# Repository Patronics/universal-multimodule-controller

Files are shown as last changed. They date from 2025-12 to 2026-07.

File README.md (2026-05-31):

# Universal Multi-Module Controller

This project aims to allow standard input devices (such as game controllers and keyboards) to control output to 4-in-one multi-module transmitters.

Created by Patrick Leiser and Josh Adriano.

## Installation
Use the [Arduino-Pico board core](https://arduino-pico.readthedocs.io/en/latest/) by Earle Philhower
Dependencies:
U8g2 by oliver
ArduinoJson by Benoit Blanchon
Bounce2 by Thomas O Fredericks
Pico PIO USB by Sekigon-gonnoc

You can program it with the Arduino IDE directly, adjust the menu options as described at the top of `GamesteerRC.ino`.

Alternatively, for advanced usage and debugging, you can install the [Arduino-CLI](https://docs.arduino.cc/arduino-cli/) and use the scripts as described below: 

## Build & Debug Scripts

---

### build.sh  
Builds a **release version** of the firmware using Arduino CLI.

- Optimized for performance (`-O2` / `-Os`)
- Produces `.elf` and `.uf2` in `build/`
- Use when you want final or production-like firmware

---

### debug-build.sh  
Builds a **debug version** of the firmware.

- Uses `-Og` optimization for good debugging behavior
- Includes full debug symbols (`-g`)
- Outputs to `build-debug/`
- Use when stepping through code or inspecting variables with GDB

---

### flash.sh  
Flashes firmware using the **Raspberry Pi Debug Probe (OpenOCD + SWD)**.

- Programs the `.elf` directly to flash
- Verifies and resets the device
- Use for fast iteration during debugging

---

### openocd.sh  
Starts the **OpenOCD GDB server**.

- Provides a debugging connection on port 3333
- Required before connecting GDB
- Use when preparing a debug session

---

### gdb.sh  
Launches **GDB for source-level debugging**.

- Connects to OpenOCD (`localhost:3333`)
- Uses the project `.elf`
- Use for breakpoints, stepping, and inspecting state
- See debugging section below for additional details
---

### upload.sh  
Flashes firmware using the **UF2 bootloader (USB mode)**.
- uses `arduino-cli upload`
- Before use, edit upload.sh with the port of your target device, such as `/dev/cu.usbmodem101` or `COM7`
  - Alternatively, you can manually boot the device into BOOTSEL mode, and copy `build/GamesteerRC.ino.uf2` onto the device.
- No debugger needed
- Use for simple deployment or recovery
---

### Typical usage
Call the scripts from the top level of the directory, such as `./scripts/build.sh`
- **Development (debugging):** `debug-build.sh` → `flash.sh` → `openocd.sh` → *(in a second terminal session)* `gdb.sh`
- **Quick standalone flash:** `build.sh → upload.sh`

## Debugging
For debugging, once OpenOCD and GDB are active, within GDB run 
```gdb
target extended-remote :3333
monitor reset halt
break panic
continue

```

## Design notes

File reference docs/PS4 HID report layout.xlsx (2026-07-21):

PS4 HID report layout
Byte index | Sample Report Value | Input Name | Bit mask | notes
0 | 01
1 | 76 | LX | FF | fully supported analog input
2 | 80 | LY | FF | fully supported analog input
3 | 7E | RX | FF | fully supported analog input
4 | 80 | RY | FF | fully supported analog input
5 | 08 |  | 10 | Square button
 |  |  | 20 | X button
 |  |  | 40 | Circle button
 |  |  | 80 | Triangle Button
 |  |  | 0F | D-pad: 08=unpressed, 00 through 07= Directions and diagonals clockwise from up
6 | 00 |  | 01 | L1 Pressed
 |  |  | 02 | R1 Pressed
 |  |  | 10 | Share button pressed
 |  |  | 20 | Options button pressed
 |  |  | 40 | Left Joystick (L3) pressed
 |  |  | 80 | Right Joystick (R3) pressed
7 | 60 |  | FC | Report counter, increments with each incoming report
8 | 00 | LT | FF | fully supported analog input (L2)
9 | 00 | RT | FF | fully supported analog input (R2)
10 | 7F |  |  | Start of Gyro/Accel data?
11 | B4 |  |  | Continued gyro/accel data?
12 | 0C |  |  | Continued gyro/accel data?
13 | 19 |  |  | Continued gyro/accel data?
14 | 00 |  |  | Continued gyro/accel data?
15 | 0D |  |  | Continued gyro/accel data?
16 | 00 |  |  | Continued gyro/accel data?
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

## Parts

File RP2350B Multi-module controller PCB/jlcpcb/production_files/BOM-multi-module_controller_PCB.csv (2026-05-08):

Comment | Designator | Footprint | LCSC | Quantity
0 | R10 | R_0402_1005Metric | C17168 | 1
0.1u | C25 | C_0402_1005Metric | C1525 | 1
100n | C11,C12,C13,C14,C15,C16,C17,C18,C2,C20,C21,C23,C26,C8 | C_0402_1005Metric | C1525 | 14
10k | R15,R16 | R_0402_1005Metric | C25744 | 2
10u | C1,C19,C5 | C_0805_2012Metric | C15850 | 3
15p | C3,C4 | C_0402_1005Metric | C7467172 | 2
1k | R2,R4,R6 | R_0402_1005Metric | C11702 | 3
22 | R20,R21,R22,R26 | R_0402_1005Metric | C25092 | 4
27 | R7,R8 | R_0402_1005Metric | C25100 | 2
3.3u | L1 | L_pol_2016 | C42411119 | 1
33 | R3 | R_0402_1005Metric | C25105 | 1
33k | R14,R18 | R_0402_1005Metric | C25779 | 2
4.7u | C10,C6,C7,C9 | C_0402_1005Metric | C23733 | 4
470 | R25 | R_0603_1608Metric | C23179 | 1
47k | R17,R19 | R_0402_1005Metric | C25792 | 2
47u | C24,C27 | C_1206_3216Metric | C96123 | 2
56k | R23,R24 | R_0402_1005Metric | C2906875 | 2
5k1 | R12,R5 | R_0402_1005Metric | C25905 | 2
ABM8-272-T3 | Y1 | Crystal_SMD_3225-4Pin_3.2x2.5mm | C20625731 | 1
BTN_BACK | SW8 | SW_Push_1P1T_NO_E-Switch_TL3301NxxxxxG | C2837532 | 1
BTN_DOWN | SW6 | SW_Push_1P1T_NO_E-Switch_TL3301NxxxxxG | C2837532 | 1
BTN_LEFT | SW3 | SW_Push_1P1T_NO_E-Switch_TL3301NxxxxxG | C2837532 | 1
BTN_MDL | SW10 | SW_Push_1P1T_NO_E-Switch_TL3301NxxxxxG | C2837532 | 1
BTN_OK | SW5 | SW_Push_1P1T_NO_E-Switch_TL3301NxxxxxG | C2837532 | 1
BTN_RIGHT | SW7 | SW_Push_1P1T_NO_E-Switch_TL3301NxxxxxG | C2837532 | 1
BTN_SYS | SW9 | SW_Push_1P1T_NO_E-Switch_TL3301NxxxxxG | C2837532 | 1
BTN_UP | SW4 | SW_Push_1P1T_NO_E-Switch_TL3301NxxxxxG | C2837532 | 1
FSUSB42MUX | U5 | MSOP-10_3x3mm_P0.5mm | C11355 | 1
LED | D1 | LED_0603_1608Metric | C7496818 | 1
MIC2026-1xM | U6 | SOIC-8_3.9x4.9mm_P1.27mm | C144190 | 1
Module_Bay | J7 | PinHeader_1x08_P2.54mm_Vertical | C19184340 | 1
NCP1117-3.3_SOT223 | U2 | SOT-223-3_TabPin2 | C88234 | 1
RP2350_80QFN | U1 | RP2350-QFN-80-1EP_10x10_P0.4mm_EP3.4x3.4mm_ThermalVias | C42415655 | 1
SW_Push | SW1,SW2 | SW_Push_1P1T_NO_Vertical_Wuerth_434133025816 | C2910644 | 2
USB_A | J8 | USB_A_Connfly_DS1095 | C456018 | 1
USB_C_Receptacle_USB2.0_14P | J5,J6 | USB_C_Receptacle_G-Switch_GT-USB-7010ASV | C2988369 | 2
W25Q128JVS | U3 | SOIC-8_5.23x5.23mm_P1.27mm | C97521 | 1
~ | DS1 | Waveshare 1.54in OLED |  | 1
SM03B-SRSS-TB | J4 | PinHeader_1x03_P2.54mm_Vertical |  | 1
DNF | R1 | R_0402_1005Metric |  | 1
MountingHole | H2 | MountingHole_2.7mm_M2.5 |  | 1
MountingHole | H3 | MountingHole_2.7mm_M2.5 |  | 1
MountingHole | H1 | MountingHole_2.7mm_M2.5 |  | 1
MountingHole | H4 | MountingHole_2.7mm_M2.5 |  | 1
DNF | R9 | R_0402_1005Metric |  | 1
DNF | U4 | SOIC-8_5.23x5.23mm_P1.27mm |  | 1
DNF | R11 | R_0402_1005Metric |  | 1
DNF | R13 | R_0402_1005Metric |  | 1
DNF | C22 | C_0402_1005Metric |  | 1
ADC_Breakout | J9 | PinHeader_2x09_P2.54mm_Vertical |  | 1
Conn_02x06_Odd_Even | J1 | PinSocket_2x06_P2.54mm_Vertical |  | 1
Internal unused GPIO Breakout | J10 | PinHeader_2x03_P1.27mm_Vertical |  | 1

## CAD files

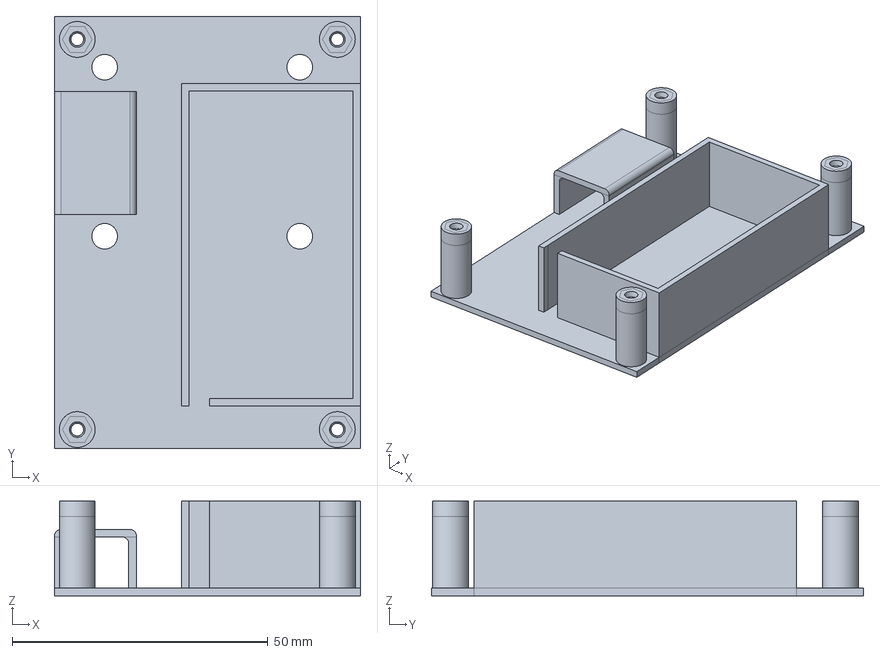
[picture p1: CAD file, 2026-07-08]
3D models/Case.FCStd
59.8 x 84.4 x 18.5 mm

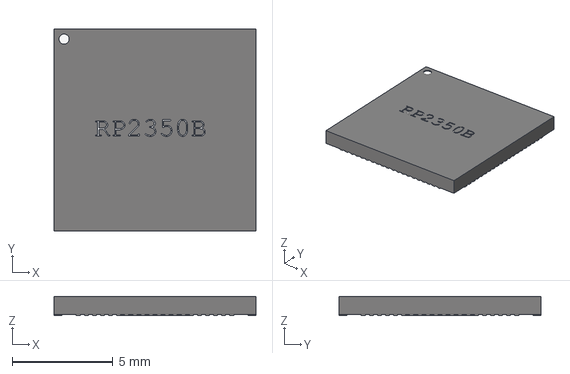
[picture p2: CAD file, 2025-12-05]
RP2350B Multi-module controller PCB/RP2350_QFN80.step
10.0 x 10.0 x 0.95 mm

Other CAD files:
3D models/PCBv1-1.step

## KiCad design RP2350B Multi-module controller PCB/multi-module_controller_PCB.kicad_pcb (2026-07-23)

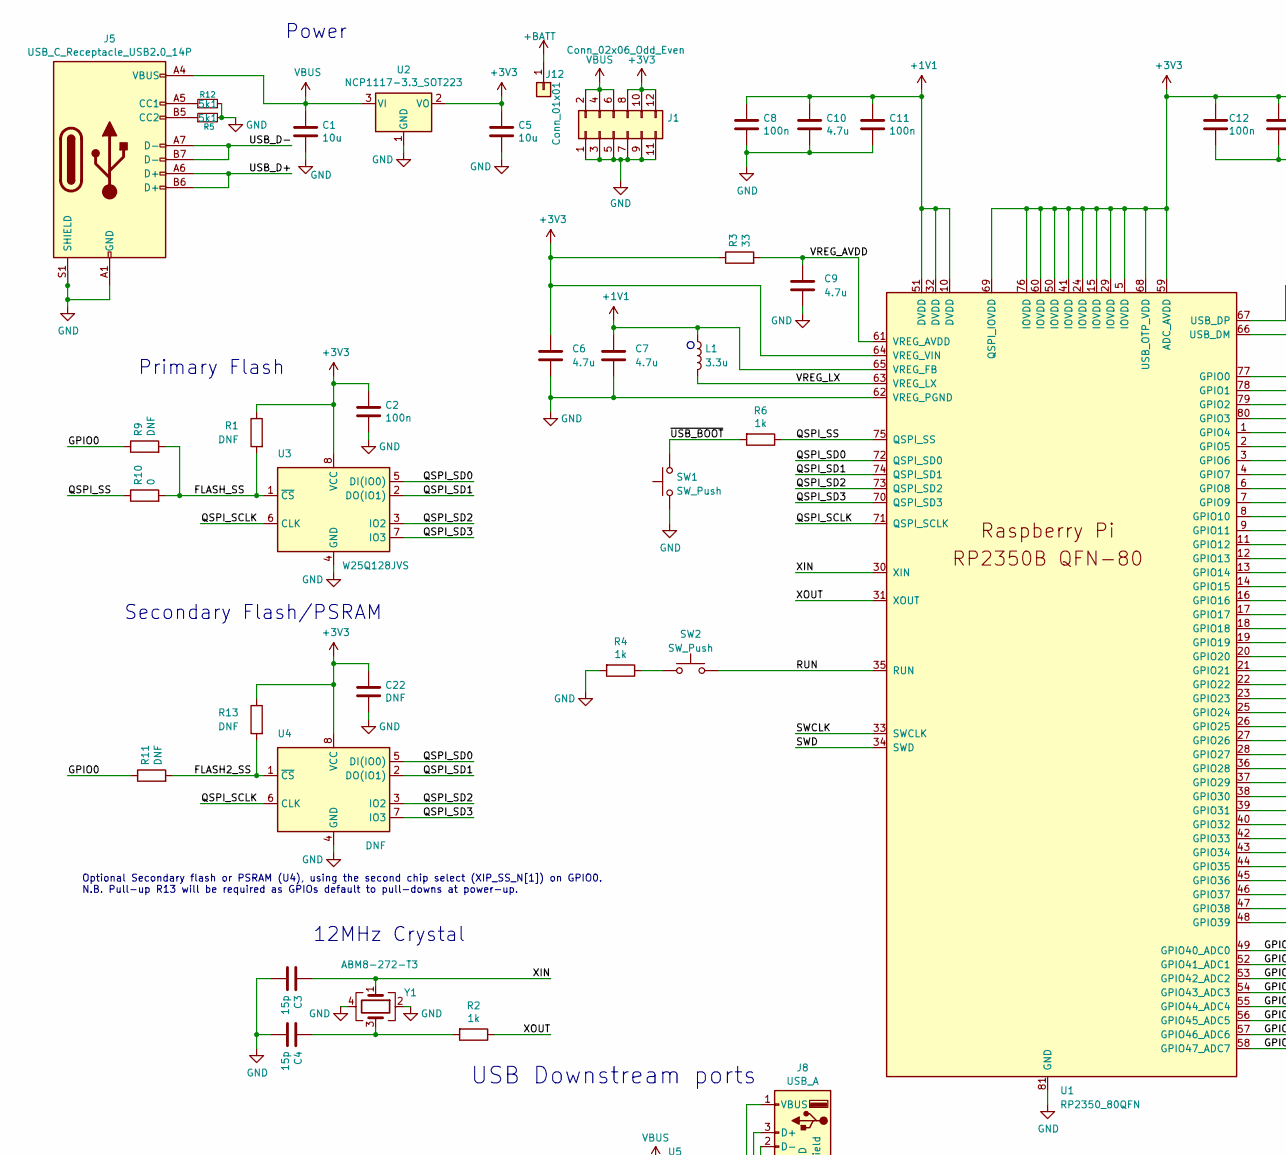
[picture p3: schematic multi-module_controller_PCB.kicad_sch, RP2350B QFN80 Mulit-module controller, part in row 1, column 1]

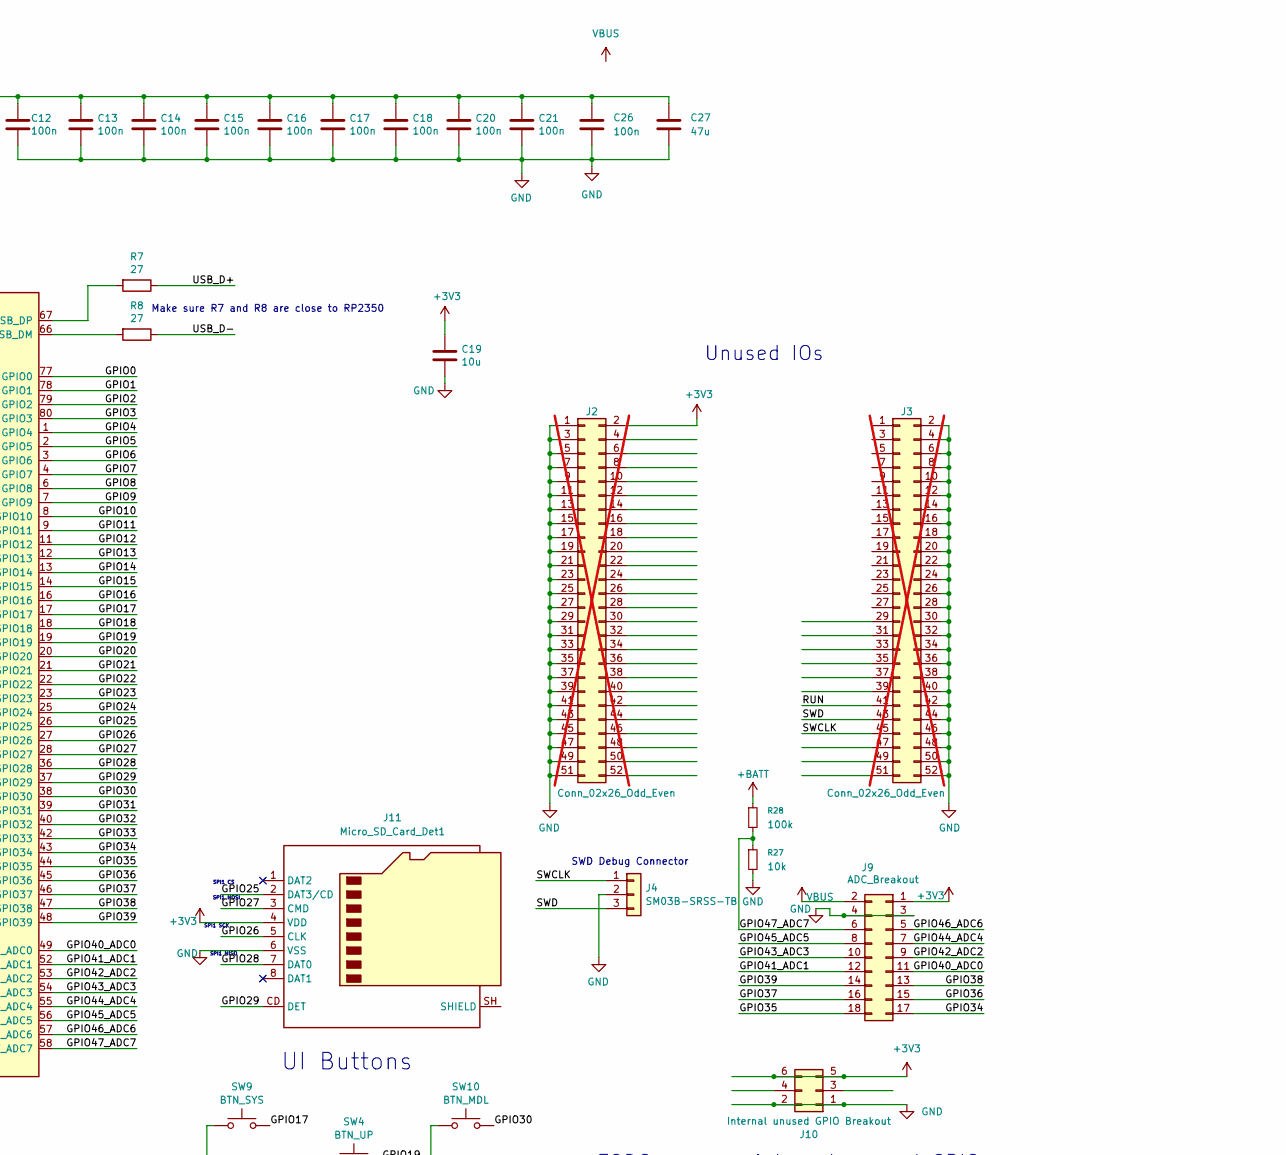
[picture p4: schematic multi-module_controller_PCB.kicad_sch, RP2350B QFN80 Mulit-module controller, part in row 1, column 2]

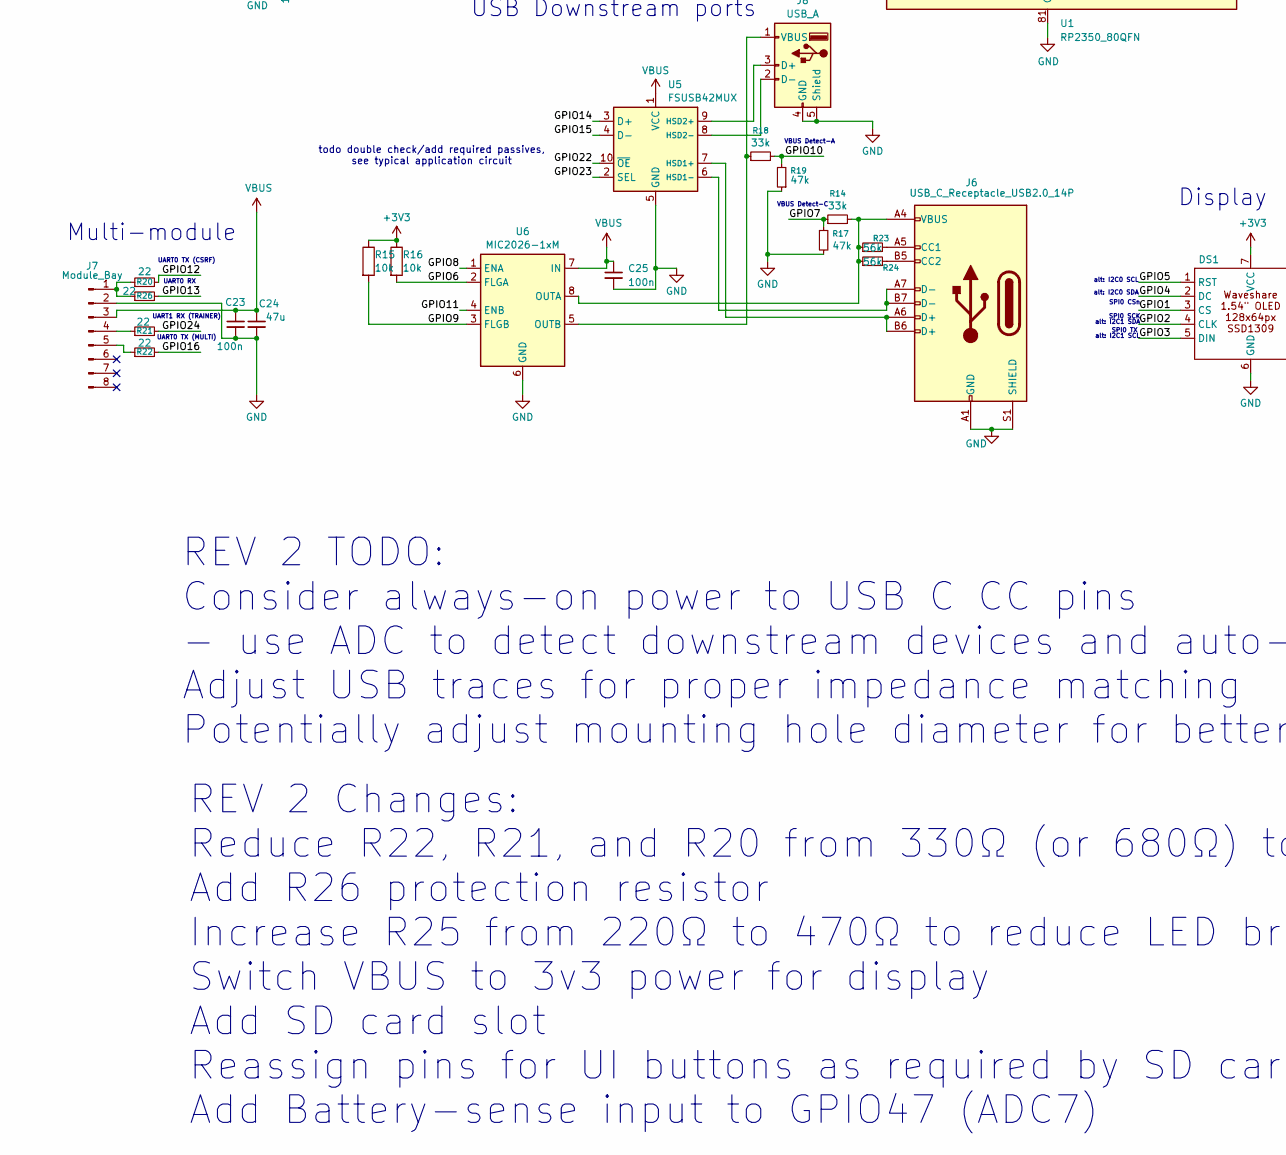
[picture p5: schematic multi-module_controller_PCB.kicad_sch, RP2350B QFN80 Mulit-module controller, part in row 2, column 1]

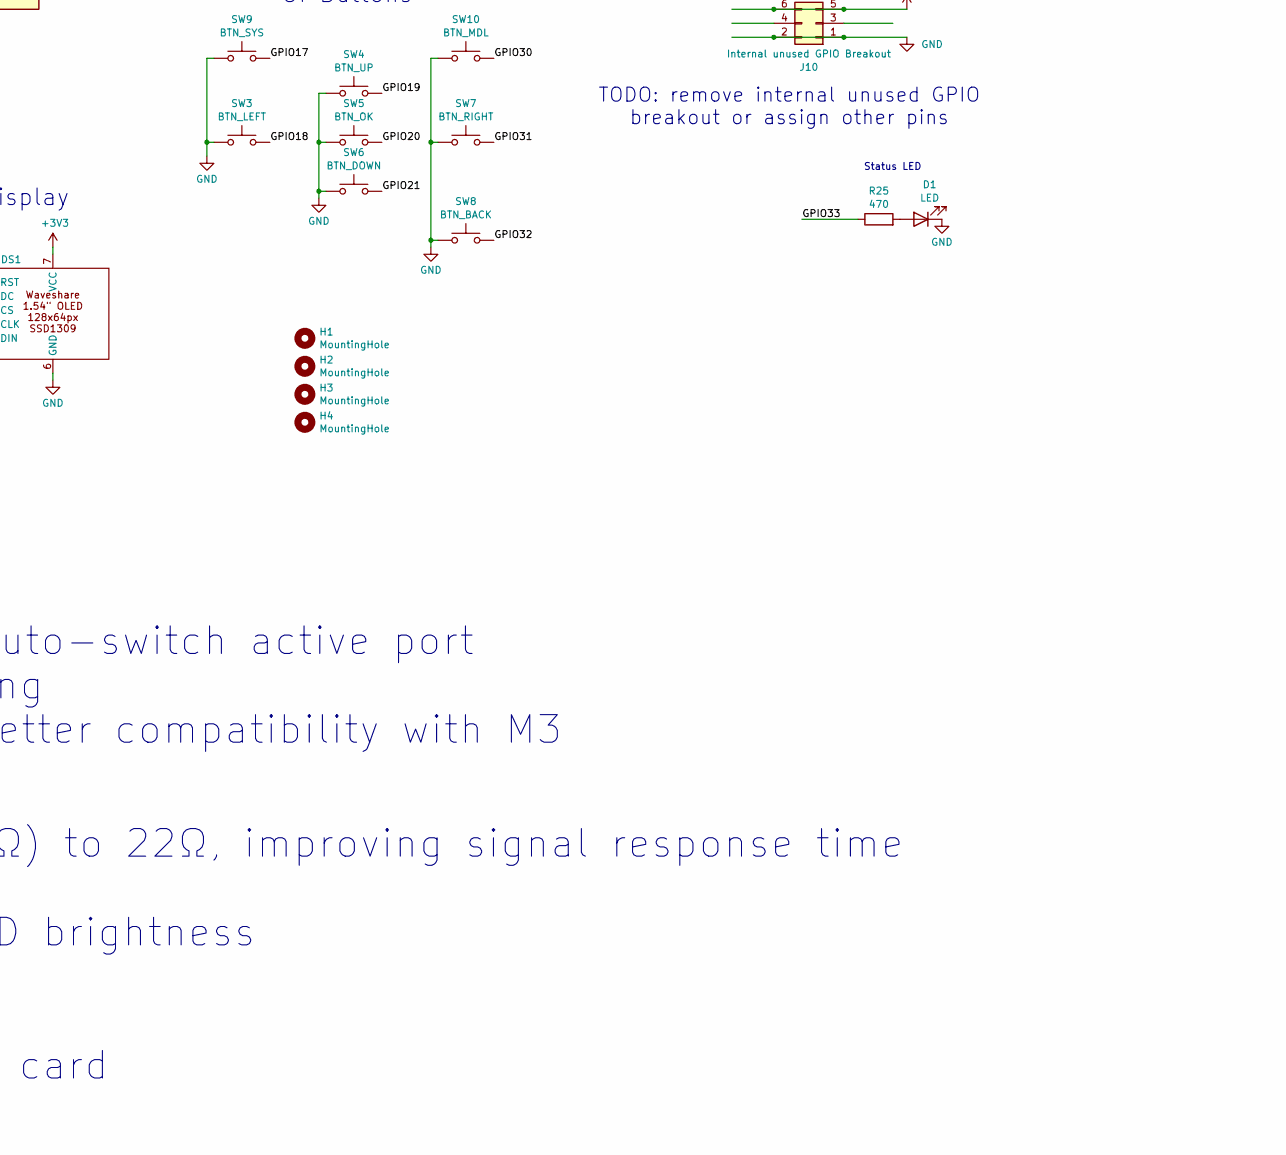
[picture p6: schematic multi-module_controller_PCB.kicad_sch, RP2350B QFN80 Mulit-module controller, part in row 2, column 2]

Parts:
C1, C5, C19: 10u; C_0805_2012Metric; LCSC C15850
C2, C8, C11, C12, C13, C14, C15, C16, C17, C18, C20, C21, C23, C25: 100n; C_0402_1005Metric; LCSC C1525
C3, C4: 15p; C_0402_1005Metric; LCSC C7467172
C6, C7: 4.7u; C_0402_1005Metric_small_pads; LCSC C23733
C9, C10: 4.7u; C_0402_1005Metric; LCSC C23733
C22: DNF; C_0402_1005Metric
C24: 47u; C_1206_3216Metric; LCSC C16780
C26: 100n; C_0402_1005Metric
C27: 47u; C_1206_3216Metric
D1: LED; LED_0603_1608Metric; LCSC C7496818
DS1: Waveshare 1.54in OLED
H1, H2, H3, H4: MountingHole; MountingHole_3.2mm_M3
J1: Conn_02x06_Odd_Even; PinSocket_2x06_P2.54mm_Vertical
J2, J3: Conn_02x26_Odd_Even; PinHeader_2x26_P2.54mm_Vertical; not fitted
J4: SM03B-SRSS-TB; PinHeader_1x03_P2.54mm_Vertical
J5, J6: USB_C_Receptacle_USB2.0_14P; USB_C_Receptacle_G-Switch_GT-USB-7010ASV; LCSC C2988369
J7: Module_Bay; PinHeader_1x08_P2.54mm_Vertical; LCSC C19184340
J8: USB_A; USB_A_Connfly_DS1095; LCSC C456018
J9: ADC_Breakout; PinHeader_2x09_P2.54mm_Vertical
J10: Internal unused GPIO Breakout; PinHeader_2x03_P1.27mm_Vertical
J11: Micro_SD_Card_Det1; SD-SMD_MLD-TF-PUSH-H18
J12: Conn_01x01; PinHeader_1x01_P2.54mm_Vertical
L1: 3.3u; L_pol_2016; LCSC C42411119
R1, R9, R11, R13: DNF; R_0402_1005Metric
R2, R4, R6: 1k; R_0402_1005Metric; LCSC C11702
R3: 33; R_0402_1005Metric; LCSC C25105
R5, R12: 5k1; R_0402_1005Metric; LCSC C25905
R7, R8: 27; R_0402_1005Metric; LCSC C25100
R10: 0; R_0402_1005Metric; LCSC C17168
R14, R18: 33k; R_0402_1005Metric; LCSC C25744
R15, R16: 10k; R_0402_1005Metric; LCSC C25744
R17, R19: 47k; R_0402_1005Metric; LCSC C25792
R20, R26: 22; R_0402_1005Metric; LCSC C25130
R21, R22: 22; R_0402_1005Metric; LCSC C25104
R23, R24: 56k; R_0402_1005Metric; LCSC C2906875
R25: 470; R_0603_1608Metric; LCSC C22962
R27: 10k; R_0402_1005Metric
R28: 100k; R_0402_1005Metric
SW1, SW2: SW_Push; SW_Push_1P1T_NO_Vertical_Wuerth_434133025816; LCSC C2910644
SW3: BTN_LEFT; SW_Push_1P1T_NO_E-Switch_TL3301NxxxxxG; LCSC C2837532
SW4: BTN_UP; SW_Push_1P1T_NO_E-Switch_TL3301NxxxxxG; LCSC C2837532
SW5: BTN_OK; SW_Push_1P1T_NO_E-Switch_TL3301NxxxxxG; LCSC C2837532
SW6: BTN_DOWN; SW_Push_1P1T_NO_E-Switch_TL3301NxxxxxG; LCSC C2837532
SW7: BTN_RIGHT; SW_Push_1P1T_NO_E-Switch_TL3301NxxxxxG; LCSC C2837532
SW8: BTN_BACK; SW_Push_1P1T_NO_E-Switch_TL3301NxxxxxG; LCSC C2837532
SW9: BTN_SYS; SW_Push_1P1T_NO_E-Switch_TL3301NxxxxxG; LCSC C2837532
SW10: BTN_MDL; SW_Push_1P1T_NO_E-Switch_TL3301NxxxxxG; LCSC C2837532
U1: RP2350_80QFN; RP2350-QFN-80-1EP_10x10_P0.4mm_EP3.4x3.4mm_ThermalVias; LCSC C42415655
U2: NCP1117-3.3_SOT223; SOT-223-3_TabPin2; LCSC C88234
U3: W25Q128JVS; SOIC-8_5.23x5.23mm_P1.27mm; LCSC C97521
U4: DNF; SOIC-8_5.23x5.23mm_P1.27mm
U5: FSUSB42MUX; MSOP-10_3x3mm_P0.5mm; LCSC C11355
U6: MIC2026-1xM; SOIC-8_3.9x4.9mm_P1.27mm; LCSC C144190
Y1: ABM8-272-T3; Crystal_SMD_3225-4Pin_3.2x2.5mm; LCSC C20625731

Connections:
+1V1: C7.1, C8.1, C10.1, C11.1, L1.1, U1.10 (DVDD), U1.32 (DVDD), U1.51 (DVDD), U1.65 (VREG_FB)
+3V3: C2.1, C5.1, C6.1, C12.1, C13.1, C14.1, C15.1, C16.1, C17.1, C18.1, C19.1, C20.1, C21.1, C22.1, C26.1, C27.1, DS1.7 (VCC), J1.8, J1.10, J1.12, J2.2, J9.1, J10.5, J10.6, J11.4 (VDD), R1.1, R3.1, R13.1, R15.1, R16.1, U1.5 (IOVDD), U1.15 (IOVDD), U1.24 (IOVDD), U1.29 (IOVDD), U1.41 (IOVDD), U1.50 (IOVDD), U1.59 (ADC_AVDD), U1.60 (IOVDD), U1.64 (VREG_VIN), U1.68 (USB_OTP_VDD), U1.69 (QSPI_IOVDD), U1.76 (IOVDD), U2.2 (VO), U3.8 (VCC), U4.8 (VCC)
+BATT: J12.1 (Pin_1_1), R28.1
/FLASH2_SS: R11.2, R13.2, U4.1 (~CS)
/FLASH_SS: R1.2, R9.2, R10.2, U3.1 (~CS)
/GPIO0: R9.1, R11.1, U1.77 (GPIO0)
/GPIO1: DS1.3 (CS), U1.78 (GPIO1)
/GPIO2: DS1.4 (CLK), U1.79 (GPIO2)
/GPIO3: DS1.5 (DIN), U1.80 (GPIO3)
/GPIO4: DS1.2 (DC), U1.1 (GPIO4)
/GPIO5: DS1.1 (RST), U1.2 (GPIO5)
/GPIO6: R16.2, U1.3 (GPIO6), U6.2 (FLGA)
/GPIO7: R14.1, R17.1, U1.4 (GPIO7)
/GPIO8: U1.6 (GPIO8), U6.1 (ENA)
/GPIO9: R15.2, U1.7 (GPIO9), U6.3 (FLGB)
/GPIO10: R18.2, R19.2, U1.8 (GPIO10)
/GPIO11: U1.9 (GPIO11), U6.4 (ENB)
/GPIO12: R20.2, U1.11 (GPIO12)
/GPIO13: R26.2, U1.12 (GPIO13)
/GPIO14: U1.13 (GPIO14), U5.3 (D+)
/GPIO15: U1.14 (GPIO15), U5.4 (D-)
/GPIO16: R22.2, U1.16 (GPIO16)
/GPIO17: SW9.2, U1.17 (GPIO17)
/GPIO18: SW3.2, U1.18 (GPIO18)
/GPIO19: SW4.2, U1.19 (GPIO19)
/GPIO20: SW5.2, U1.20 (GPIO20)
/GPIO21: SW6.2, U1.21 (GPIO21)
/GPIO22: U1.22 (GPIO22), U5.10 (~OE)
/GPIO23: U1.23 (GPIO23), U5.2 (SEL)
/GPIO24: R21.2, U1.25 (GPIO24)
/GPIO25: J11.2 (DAT3/CD), U1.26 (GPIO25)
/GPIO26: J11.5 (CLK), U1.27 (GPIO26)
/GPIO27: J11.3 (CMD), U1.28 (GPIO27)
/GPIO28: J11.7 (DAT0), U1.36 (GPIO28)
/GPIO29: J11.CD (DET), U1.37 (GPIO29)
/GPIO30: SW10.2, U1.38 (GPIO30)
/GPIO31: SW7.2, U1.39 (GPIO31)
/GPIO32: SW8.2, U1.40 (GPIO32)
/GPIO33: R25.1, U1.42 (GPIO33)
/GPIO34: J9.17, U1.43 (GPIO34)
/GPIO35: J9.18, U1.44 (GPIO35)
/GPIO36: J9.15, U1.45 (GPIO36)
/GPIO37: J9.16, U1.46 (GPIO37)
/GPIO38: J9.13, U1.47 (GPIO38)
/GPIO39: J9.14, U1.48 (GPIO39)
/GPIO40_ADC0: J9.11, U1.49 (GPIO40_ADC0)
/GPIO41_ADC1: J9.12, U1.52 (GPIO41_ADC1)
/GPIO42_ADC2: J9.9, U1.53 (GPIO42_ADC2)
/GPIO43_ADC3: J9.10, U1.54 (GPIO43_ADC3)
/GPIO44_ADC4: J9.7, U1.55 (GPIO44_ADC4)
/GPIO45_ADC5: J9.8, U1.56 (GPIO45_ADC5)
/GPIO46_ADC6: J9.5, U1.57 (GPIO46_ADC6)
/GPIO47_ADC7: J9.6, R27.1, R28.2, U1.58 (GPIO47_ADC7)
/QSPI_SCLK: U1.71 (QSPI_SCLK), U3.6 (CLK), U4.6 (CLK)
/QSPI_SD0: U1.72 (QSPI_SD0), U3.5 (DI(IO0)), U4.5 (DI(IO0))
/QSPI_SD1: U1.74 (QSPI_SD1), U3.2 (DO(IO1)), U4.2 (DO(IO1))
/QSPI_SD2: U1.73 (QSPI_SD2), U3.3 (IO2), U4.3 (IO2)
/QSPI_SD3: U1.70 (QSPI_SD3), U3.7 (IO3), U4.7 (IO3)
/QSPI_SS: R6.1, R10.1, U1.75 (QSPI_SS)
/RUN: J3.41, SW2.2, U1.35 (RUN)
/SWCLK: J3.45, J4.1, U1.33 (SWCLK)
/SWD: J3.43, J4.3, U1.34 (SWD)
/USB_D+: J5.A6 (D+), J5.B6 (D+), R7.1
/USB_D-: J5.A7 (D-), J5.B7 (D-), R8.1
/VREG_AVDD: C9.1, R3.2, U1.61 (VREG_AVDD)
/VREG_LX: L1.2, U1.63 (VREG_LX)
/XIN: C3.1, U1.30 (XIN), Y1.1
/XOUT: R2.1, U1.31 (XOUT)
/~USB_BOOT: R6.2, SW1.2
GND: C1.2, C2.2, C3.2, C4.2, C5.2, C6.2, C7.2, C8.2, C9.2, C10.2, C11.2, C12.2, C13.2, C14.2, C15.2, C16.2, C17.2, C18.2, C19.2, C20.2, C21.2, C22.2, C23.2, C24.2, C25.2, C26.2, C27.2, D1.1 (K), DS1.6 (GND), J1.1, J1.3, J1.5, J1.7, J1.9, J1.11, J2.1, J2.3, J2.5, J2.7, J2.9, J2.11, J2.13, J2.15, J2.17, J2.19, J2.21, J2.23, J2.25, J2.27, J2.29, J2.31, J2.33, J2.35, J2.37, J2.39, J2.41, J2.43, J2.45, J2.47, J2.49, J2.51, J3.2, J3.4, J3.6, J3.8, J3.10, J3.12, J3.14, J3.16, J3.18, J3.20, J3.22, J3.24, J3.26, J3.28, J3.30, J3.32, J3.34, J3.36, J3.38, J3.40, J3.42, J3.44, J3.46, J3.48, J3.50, J3.52, J4.2, J5.A1 (GND), J5.A12 (GND), J5.B1 (GND), J5.B12 (GND), J5.S1 (SHIELD), J6.A1 (GND), J6.A12 (GND), J6.B1 (GND), J6.B12 (GND), J6.S1 (SHIELD), J7.2, J8.4 (GND), J8.5 (Shield), J9.3, J9.4, J10.1, J10.2, J11.6 (VSS), R4.2, R5.2, R12.2, R17.2, R19.1, R27.2, SW1.1, SW3.1, SW4.1, SW5.1, SW6.1, SW7.1, SW8.1, SW9.1, SW10.1, U1.62 (VREG_PGND), U1.81 (GND), U2.1 (GND), U3.4 (GND), U4.4 (GND), U5.5 (GND), U6.6 (GND), Y1.2, Y1.4
unnamed: C4.1, R2.2, Y1.3
unnamed: D1.2 (A), R25.2
unnamed: J5.A5 (CC1), R12.1
unnamed: J5.B5 (CC2), R5.1
unnamed: J6.A5 (CC1), R23.2
unnamed: J6.B5 (CC2), R24.2
unnamed: J7.1, R20.1, R26.1
unnamed: J7.4, R21.1
unnamed: J7.5, R22.1
unnamed: J8.3 (D+), U5.9 (HSD2+)
unnamed: J8.2 (D-), U5.8 (HSD2-)
unnamed: J8.1 (VBUS), R18.1, U6.5 (OUTB)
unnamed: R4.1, SW2.1
unnamed: R8.2, U1.66 (USB_DM)
unnamed: R7.2, U1.67 (USB_DP)
unnamed: J6.A6 (D+), J6.B6 (D+), U5.7 (HSD1+)
unnamed: J6.A7 (D-), J6.B7 (D-), U5.6 (HSD1-)
unnamed: J6.A4 (VBUS), J6.A9 (VBUS), J6.B4 (VBUS), J6.B9 (VBUS), R14.2, R23.1, R24.1, U6.8 (OUTA)
VBUS: C1.1, C23.1, C24.1, C25.1, J1.2, J1.4, J1.6, J5.A4 (VBUS), J5.A9 (VBUS), J5.B4 (VBUS), J5.B9 (VBUS), J7.3, J9.2, U2.3 (VI), U5.1 (VCC), U6.7 (IN)

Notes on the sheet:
Optional Secondary flash or PSRAM (U4), using the second chip select (XIP_SS_N[1]) on GPIO0. N.B. Pull-up R13 will be required as GPIOs default to pull-downs at power-up.
REV 2 TODO: Consider always-on power to USB C CC pins - use ADC to detect downstream devices and auto-switch active port Adjust USB traces for proper impedance matching Potentially adjust mounting hole diameter for better compatibility with M3
Unused IOs
12MHz Crystal
SPI0 SCK
SPI1 SCK
alt: I2C0 SCL
UART0 TX (CSRF)
VBUS Detect-C
UART0 TX (MULTI)
SPI1 CS
Multi-module
UI Buttons
Status LED
Primary Flash
SPI1 MOSI
alt: I2C1 SCL
REV 2 Changes: Reduce R22, R21, and R20 from 330Ω (or 680Ω) to 22Ω, improving signal response time Add R26 protection resistor Increase R25 from 220Ω to 470Ω to reduce LED brightness Switch VBUS to 3v3 power for display Add SD card slot Reassign pins for UI buttons as required by SD card Add Batter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
USB Downstream ports
todo double check/add required passives, see typical application circuit
SWD Debug Connector
UART1 RX (TRAINER)
TODO: remove internal unused GPIO breakout or assign other pins
Make sure R7 and R8 are close to RP2350
VBUS Detect-A
Secondary Flash/PSRAM
Display
alt: I2C0 SDA
UART0 RX
alt: I2C1 SDA
Power
SPI0 CSn
SPI0 TX
SPI1 MISO

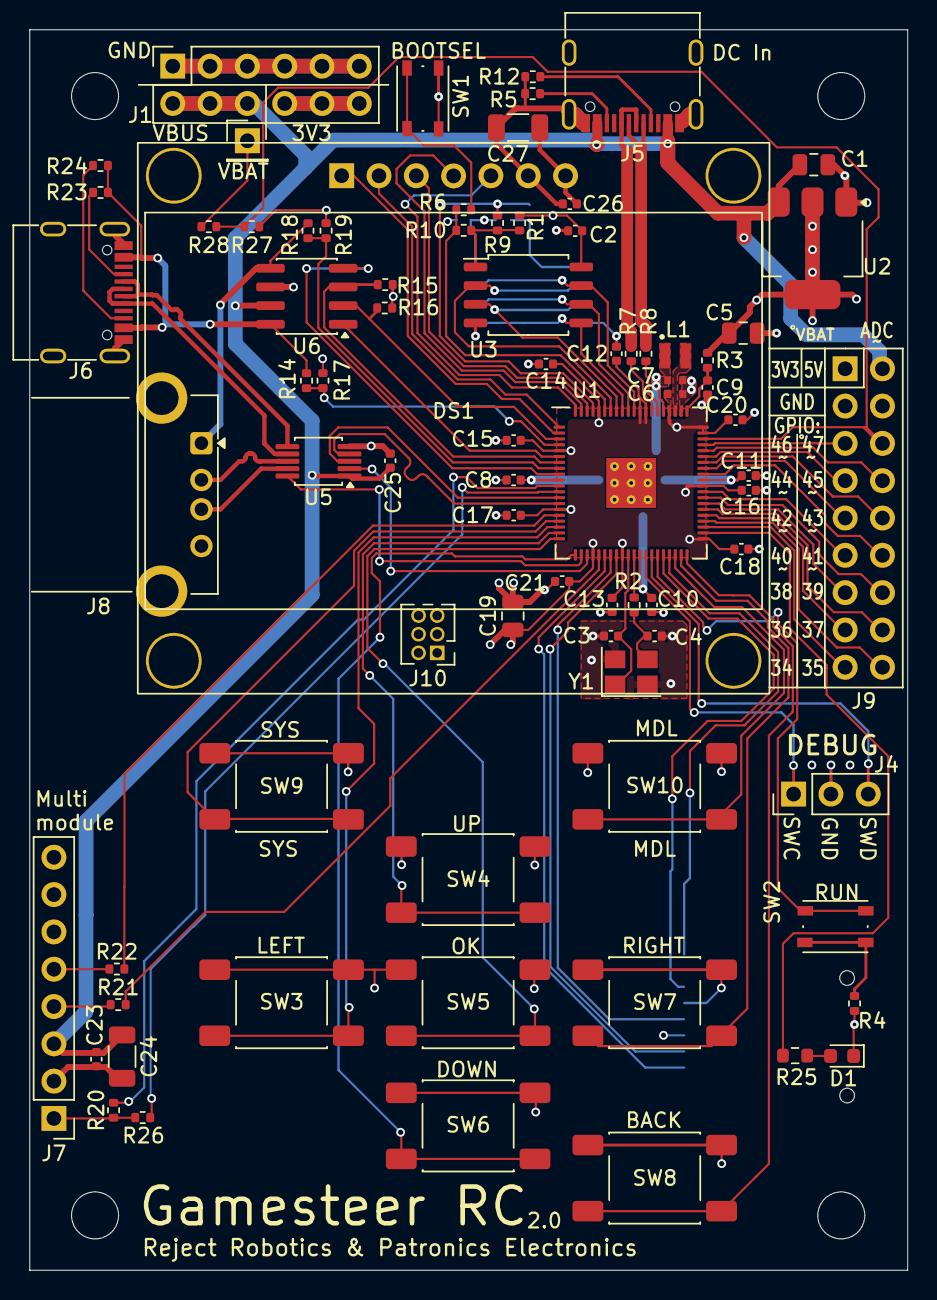
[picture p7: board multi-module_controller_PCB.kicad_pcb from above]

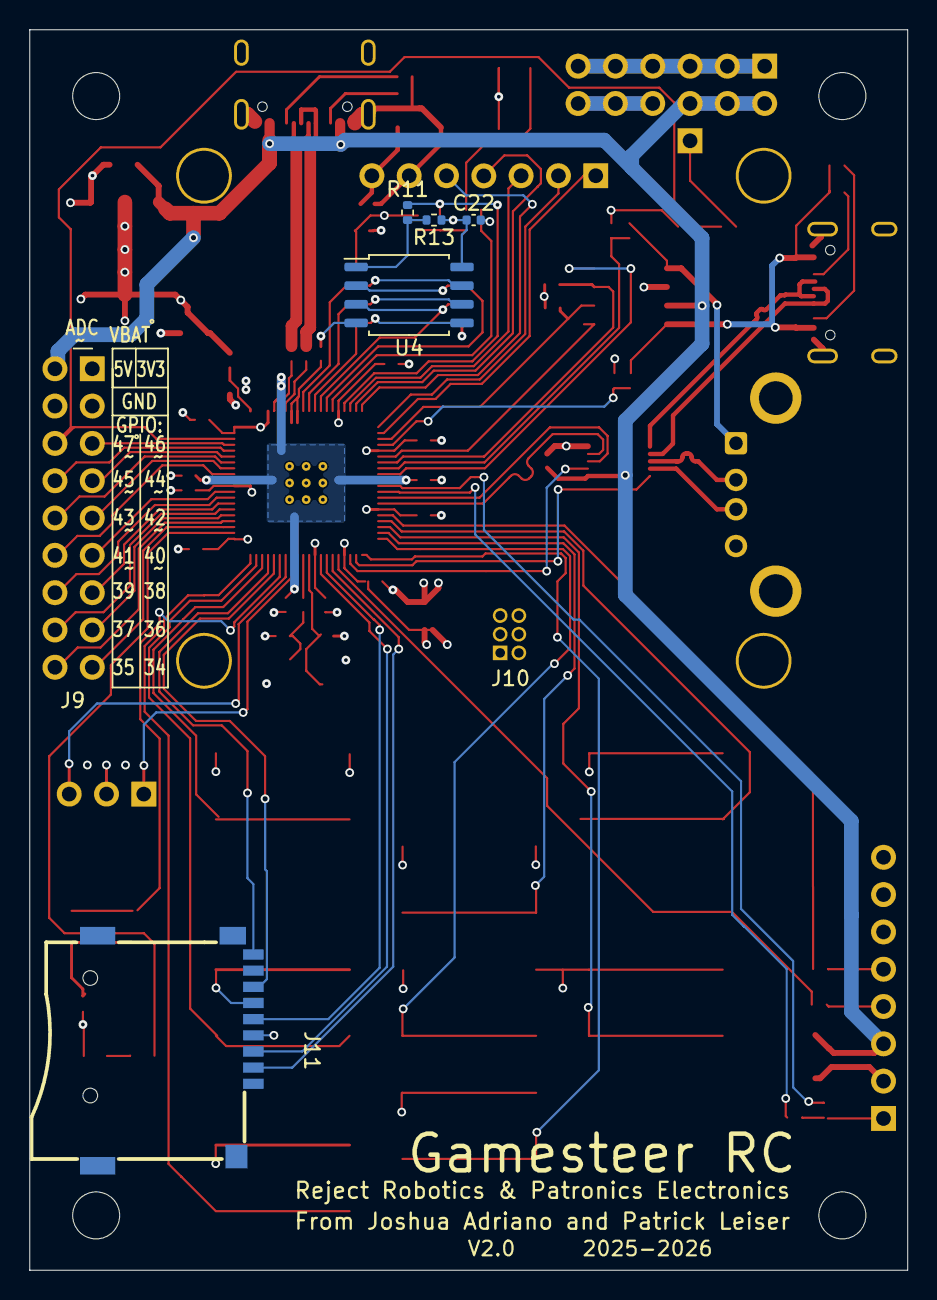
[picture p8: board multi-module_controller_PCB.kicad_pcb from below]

Board: 4 copper layers, 59.8 x 84.4 mm, 89 parts (5 on the bottom side), 89 nets.

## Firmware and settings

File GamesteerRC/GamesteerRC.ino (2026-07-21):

/*
TelemetryLogger.ino
Written By Patrick Leiser
Runs on Raspberry Pi Pico or similar RP2040 family boards
This script reads telemetry data from a 4-in-one multimodule.
*/

/*note: in arduino IDE, select:
  - Board "Raspberry Pi Pico > Generic RP2350" (from Earle Philhower)
  - Flash Size: 16MB (Sketch 8MB, FS 8MB)
  - CPU Speed: 240MHz (Overclock)
  - USB Stack: Adafruit TinyUSB
  - Chip Variant "RP2350B"
*/

//Note: DEBUG_FLAGS must be defined before including UI.h. See UI.h for list of valid flags
#define DEBUG_FLAGS (DEBUG_TRANSMIT|DEBUG_FS|DEBUG_SAVELOAD|DEBUG_LOG|DEBUG_WARN|DEBUG_ERROR|DEBUG_CORE)
//available flags: DEBUG_TIME|DEBUG_USB|DEBUG_USB_REPORT|DEBUG_TRANSMIT|DEBUG_MULTIMODULE|DEBUG_FS|DEBUG_SAVELOAD|DEBUG_LOG|DEBUG_WARN|DEBUG_ERROR|DEBUG_CORE


#include "MultiModule.h"
#include "ChannelManager.h"
#include "UI.h"
#include "controllerData.h"

// USBHost is defined in usbh_helper.h
#include "usbh_helper.h"

#include <VFS.h>
#include <LittleFS.h>
#include <ArduinoJson.h>

#include <U8g2lib.h>
#ifdef U8X8_HAVE_HW_SPI
#include <SPI.h>
#endif
#ifdef U8X8_HAVE_HW_I2C
#include <Wire.h>
#endif

#include <Bounce2.h>

//UART constants to configure:
//adjust as needed for other platforms or Serial Ports
#define SerialModule Serial1
//comment out the following defines if on a non-RP2040 platform where UART pins are fixed
#define SERIAL_MODULE_RX_PIN 13
#define SERIAL_MODULE_TX_PIN 16
#define SERIAL_MODULE_INVERT_RX


const unsigned long SERIAL_MODULE_BAUD_RATE = 100000;
const int SERIAL_MODULE_BUFFER_SIZE = 128;


unsigned long lastTelemetryMillis = 0;
unsigned long lastLoopMillis = 0;
unsigned long lastTxMillis = 0;

const unsigned long msBetweenTxUpdates = 7;

//currently unused, for saving persistient system-wide settings
struct persistent_settings {
  char enabled_port;
  uint8_t default_protocol_mode;
  uint8_t default_subprotocol_mode;
};

int current_active_model = -1;

//Select active USB port, either 'A' or 'C', or 'Z' to prompt clean-up and shutdown of the ports
volatile char requested_usb_port = 'C';
volatile char active_usb_port = requested_usb_port;
volatile bool usb_ready_flag = false; //flag set by USB core when USB device is detected and ready

OutputChannelDescriptor outChannels[MAX_CHANNELS]; //declare 16 item OutputChannelDescriptor array
MixerChannelDescriptor mixerChannels[MAX_MIXERS];
InputDescriptorPool inChannelsPool;
InputChannelDescriptor* failsafeChannels[MAX_CHANNELS];


//#define USE_I2C_DISPLAY
#define USE_PRIMARY_SPI_DISPLAY
//#define USE_SW_2ND_SPI_DISPLAY
//#define USE_HW_2ND_SPI_DISPLAY

//setup i2c display (used in pre-release hardware, slower than SPI display interfaces)
#ifdef USE_I2C_DISPLAY
  //U8G2_SSD1306_128X64_NONAME_F_HW_I2C u8g2(U8G2_R0, /* reset=*/ U8X8_PIN_NONE);
  #define I2C_DISPLAY_SDA_PIN 4
  #define I2C_DISPLAY_SCL_PIN 5
#endif

//the primary intended display interface
//for PCB 1.0, the display's VCC pin connection to VBUS MUST be bypassed, instead connect display's VCC to 3V3
#ifdef USE_PRIMARY_SPI_DISPLAY
  #define USE_HW_SPI_DISPLAY
  #define SPI_DISPLAY_RST_PIN 5
  #define SPI_DISPLAY_DC_PIN 4
  #define SPI_DISPLAY_CS_PIN 1
  #define SPI_DISPLAY_CLK_PIN 2
  #define SPI_DISPLAY_TX_PIN 3
  U8G2_SSD1309_128X64_NONAME0_F_4W_HW_SPI u8g2(U8G2_R0, SPI_DISPLAY_CS_PIN,SPI_DISPLAY_DC_PIN, SPI_DISPLAY_RST_PIN);

#endif

//convenient pinout for using display with GPIO header pins 3v3, gnd, and GPIO 46, 44, 42, 40, 38
//software-spi only so limited to 300khz clock rate
#ifdef USE_SW_2ND_SPI_DISPLAY
  #define SPI_DISPLAY_RST_PIN 38
  #define SPI_DISPLAY_DC_PIN 40
  #define SPI_DISPLAY_CS_PIN 42
  #define SPI_DISPLAY_CLK_PIN 44
  #define SPI_DISPLAY_TX_PIN 46
  U8G2_SSD1309_128X64_NONAME0_F_4W_SW_SPI u8g2(U8G2_R0, SPI_DISPLAY_CLK_PIN, SPI_DISPLAY_TX_PIN, SPI_DISPLAY_CS_PIN,SPI_DISPLAY_DC_PIN, SPI_DISPLAY_RST_PIN);
#endif

//use the gpio header pins with hardware SPI, improved performance over USE_SW_2ND_SPI_DISPLAY, but more complex pin layout
#ifdef USE_HW_2ND_SPI_DISPLAY
  #define USE_HW_SPI_DISPLAY
  #define SPI_DISPLAY_RST_PIN 46
  #define SPI_DISPLAY_DC_PIN 44
  #define SPI_DISPLAY_CS_PIN 37
  #define SPI_DISPLAY_CLK_PIN 34
  #define SPI_DISPLAY_TX_PIN 35
  U8G2_SSD1309_128X64_NONAME0_F_4W_HW_SPI u8g2(U8G2_R0, SPI_DISPLAY_CS_PIN,SPI_DISPLAY_DC_PIN, SPI_DISPLAY_RST_PIN);
#endif

#define LED_PIN 33

//UI buttons
#define OK_BUTTON_PIN 28
#define BACK_BUTTON_PIN 32
#define UP_BUTTON_PIN 27
#define DOWN_BUTTON_PIN 29
#define LEFT_BUTTON_PIN 26
#define RIGHT_BUTTON_PIN 31
#define SYS_BUTTON_PIN 25
#define MDL_BUTTON_PIN 30

const uint16_t BUTTON_DEBOUNCE_INTERVAL = 5;
#define BUTTON_INPUT_TYPE INPUT_PULLUP
#define BUTTON_PRESSED_STATE LOW

Bounce2::Button okButton;
Bounce2::Button backButton;
Bounce2::Button upButton;
Bounce2::Button downButton;
Bounce2::Button leftButton;
Bounce2::Button rightButton;
Bounce2::Button sysButton;
Bounce2::Button mdlButton;

//for picking a menu
int selectedMenu = 0;
//the currently open menu, or -1 for none
int currentMenu = -1;

const int CURRENT_MENU_NONE = -1;

int menuSubpageIndex = 0;  //for arbitrary use by sub-menu logic, should be reset to zero on exit from submenu
void *menuSubpageContext = NULL; //for arbitrary use for more advanced state in submenu logic, should be properly freed on exit of submenu
int menuUpdateCycleCount =0; //counter to update menu periodically if needed

menuItem sysMenu[MENU_ITEM_COUNT];
menuItem mdlMenu[MENU_ITEM_COUNT];

menuItem* menuItems = mdlMenu;


// USB Language ID: English
#define LANGUAGE_ID 0x0409

// CFG_TUH_DEVICE_MAX is defined by tusb_config header
usb_dev_info_t usb_raw_descriptors[CFG_TUH_DEVICE_MAX] = { 0 };

USBInputDeviceDescriptor USBDeviceDescriptors[MAX_USB_DEVICE_DESCRIPTORS];
uint8_t numberOfDeviceDescriptors = 0;

//data structures for status and output
char capturedData[MAX_TELEM_DATA_BYTES + 1]; // Pre-allocated buffer, +1 for null-terminator
MultiModuleStatus moduleStatus;

MultiProtocolStream streamOut;
uint8_t streamOutAdditionalProtocolDataLen = 0;

uint8_t currentActiveProtocol = 0;
uint8_t currentActiveSubProtocol = 0;

bool transmitActive = false;
bool failsafeActive = false;
bool haveTelemetry = false;




void setup() {

  Serial.begin(115200); //init USB serial
  pinMode(LED_PIN,OUTPUT);
  digitalWrite(LED_PIN, HIGH);

  //bounce2 setup
  okButton.attach(OK_BUTTON_PIN, BUTTON_INPUT_TYPE);
  backButton.attach(BACK_BUTTON_PIN, BUTTON_INPUT_TYPE);
  upButton.attach(UP_BUTTON_PIN, BUTTON_INPUT_TYPE);
  downButton.attach(DOWN_BUTTON_PIN, BUTTON_INPUT_TYPE);
  leftButton.attach(LEFT_BUTTON_PIN, BUTTON_INPUT_TYPE);
  rightButton.attach(RIGHT_BUTTON_PIN, BUTTON_INPUT_TYPE);
  sysButton.attach(SYS_BUTTON_PIN, BUTTON_INPUT_TYPE);
  mdlButton.attach(MDL_BUTTON_PIN, BUTTON_INPUT_TYPE);

  //debounce interval
  okButton.interval(BUTTON_DEBOUNCE_INTERVAL);
  backButton.interval(BUTTON_DEBOUNCE_INTERVAL);
  upButton.interval(BUTTON_DEBOUNCE_INTERVAL);
  downButton.interval(BUTTON_DEBOUNCE_INTERVAL);
  leftButton.interval(BUTTON_DEBOUNCE_INTERVAL);
  rightButton.interval(BUTTON_DEBOUNCE_INTERVAL);
  sysButton.interval(BUTTON_DEBOUNCE_INTERVAL);
  mdlButton.interval(BUTTON_DEBOUNCE_INTERVAL);

  okButton.setPressedState(BUTTON_PRESSED_STATE);
  backButton.setPressedState(BUTTON_PRESSED_STATE);
  upButton.setPressedState(BUTTON_PRESSED_STATE);
  downButton.setPressedState(BUTTON_PRESSED_STATE);
  leftButton.setPressedState(BUTTON_PRESSED_STATE);
  rightButton.setPressedState(BUTTON_PRESSED_STATE);
  sysButton.setPressedState(BUTTON_PRESSED_STATE);
  mdlButton.setPressedState(BUTTON_PRESSED_STATE);

  //set i2c pins for display
  #ifdef USE_I2C_DISPLAY
    Wire.setSDA(I2C_DISPLAY_SDA_PIN);
    Wire.setSCL(I2C_DISPLAY_SCL_PIN);
  #endif
  //setup SPI pins for display
  #ifdef USE_HW_SPI_DISPLAY
    SPI.setRX(NOPIN);
    SPI.setTX(SPI_DISPLAY_TX_PIN);
    SPI.setSCK(SPI_DISPLAY_CLK_PIN);
    SPI.setCS(SPI_DISPLAY_CS_PIN);
    //u8g2.setBusClock(1000000); //1Mhz, fallback value for debugging
    u8g2.setBusClock(8000000); //8Mhz
  #endif
  //otherwise use software SPI display, not setup required:
  /*#ifdef USE_SW_2ND_SPI_DISPLAY
    bit-banged SPI does not support setBusClock configuration
    it runs at around 300kHz in my testing
  #endif*/
 
  u8g2.begin();
  u8g2.setFont(u8g2_font_tom_thumb_4x6_mf);
  u8g2.setCursor(0, 6);
  u8g2.print("GameSteer RC starting");
  u8g2.sendBuffer();
  //initialize SerialModule on GPIO 16 and 17 (pins 21 and 22), at 100kbaud, even parity, 2 stop bits
  #ifdef SERIAL_MODULE_RX_PIN
    SerialModule.setRX(SERIAL_MODULE_RX_PIN);
  #endif
  #ifdef SERIAL_MODULE_TX_PIN
    SerialModule.setTX(SERIAL_MODULE_TX_PIN);
  #endif
  #ifdef SERIAL_MODULE_INVERT_RX
    SerialModule.setInvertRX(true);
  #endif
  SerialModule.setFIFOSize(SERIAL_MODULE_BUFFER_SIZE);
  SerialModule.begin(SERIAL_MODULE_BAUD_RATE, SERIAL_8E2);
  //initialize stream values
  //start setting up output data structures
  streamOut.header.reserved_bits=0b010101;
  streamOut.header.is_failsafe = 0;
  setProtocolMode(&streamOut, 28, 0); //default protocol, 28=AFHDS2A, 0=PWM_IBUS
  streamOut.rx_num_power_type.rxNum = 0;
  streamOut.rx_num_power_type.power = 0; //high power
  streamOut.option_protocol = -128; //unknown purpose, matching example from transmitter for now
  streamOut.extended_protocol.telemetry_Invert = 1;
  u8g2.setCursor(0, 12);
  u8g2.print("Serial Module setup");
  u8g2.sendBuffer();
  /*while (!Serial) {
    ; // wait for USB serial port to connect
  }*/

  SerialDebug<DEBUG_LOG>("Serial Debugging enabled: log level ");
  SerialDebug<DEBUG_LOG>(debug_flags);
  SerialDebug<DEBUG_LOG>("\n");

  if(!LittleFS.begin()){
    SerialDebug<DEBUG_ERROR>("FS begin failed");
  } else {
    VFS.root(LittleFS);
    FSInfo fs_info;
    if (!LittleFS.info(fs_info)) {
      SerialDebug<DEBUG_WARN>("FS info() failed");
    } else {
      if(debug_level<DEBUG_FS>()){
        Serial.println("LittleFS info:");
        Serial.print("  totalBytes:     "); Serial.println((unsigned long long)fs_info.totalBytes);
        Serial.print("  usedBytes:      "); Serial.println((unsigned long long)fs_info.usedBytes);
        Serial.print("  blockSize:      "); Serial.println((size_t)fs_info.blockSize);
        Serial.print("  pageSize:       "); Serial.println((size_t)fs_info.pageSize);
        Serial.print("  maxOpenFiles:   "); Serial.println((size_t)fs_info.maxOpenFiles);
        Serial.print("  maxPathLength:  "); Serial.println((size_t)fs_info.maxPathLength);
      }
    }
  }

  Serial.println("starting.");
  
  //initDefaultInputDescriptors(&inChannelsPool);
  initOutputAndDefaultInputChannelDescriptors(outChannels, &inChannelsPool, mixerChannels, failsafeChannels);
  
  u8g2.setCursor(0, 18);
  u8g2.print("loading default settings");
  u8g2.sendBuffer();
  u8g2.setCursor(0, 24);
  loadDefaultSettings(true);
  u8g2.setCursor(0, 30);
  u8g2.print("ready");
  u8g2.sendBuffer();
  //Serial.print("output struct:");
  //printStructWithLenAsHex(&streamOut, (sizeof(streamOut)-(9-streamOutAdditionalProtocolDataLen)));
  u8g2.clearBuffer();
  setupMenuLayout();
  redrawMenu(0, -1);
  digitalWrite(LED_PIN, LOW);
}

//core 1 is dedicated to USB host actions
//------------- Core1 -------------//
void setup1() {
  // configure pio-usb: defined in usbh_helper.h
  //Select active USB port, either 'A' or 'C'
  disable_usb();
  delay(1000);
  SerialDebugln<DEBUG_CORE>("Core1 setup to run TinyUSB host with pio-usb");
  rp2040_configure_pio_usb(active_usb_port);
  // run host stack on controller (rhport) 1
  // Note: For rp2040 pico-pio-usb, calling USBHost.begin() on core1 will have most of the
  // host bit-banging processing works done in core1 to free up core0 for other works
  USBHost.begin(1);
}

void loop1() {
  //valid requested USB ports are A, C, and Z (disabled).
  if (requested_usb_port != active_usb_port){
    SerialDebugln<DEBUG_LOG>("Updating active USB port!");
    disable_usb();
    delay(1000);
    USBHost.task();
    USBHost.task();
    USBHost.task();
    if(requested_usb_port == 'A' || requested_usb_port=='C'){
      change_active_usb_port(requested_usb_port);
    }
    active_usb_port = requested_usb_port;

  } else if(active_usb_port == 'A' || active_usb_port == 'C') {
    USBHost.task();
  }
}

//core zero runs all non-usb tasks
void loop() {
  // Update each button's state
  okButton.update();
  backButton.update();
  upButton.update();
  downButton.update();
  leftButton.update();
  rightButton.update();
  sysButton.update();
  mdlButton.update();

  NavButton currentNavButton = NO_BUTTON_PRESSED;
  if (okButton.pressed()) {
    currentNavButton = OK_BUTTON;
  }
  if (backButton.pressed()) {
    currentNavButton = BACK_BUTTON;
  }
  if (upButton.pressed()) {
    currentNavButton = UP_BUTTON;
  }
  if (downButton.pressed()) {
    currentNavButton = DOWN_BUTTON;
  }
  if (leftButton.pressed()) {
    currentNavButton = LEFT_BUTTON;
  }
  if (rightButton.pressed()) {
    currentNavButton = RIGHT_BUTTON;
  }
  if (sysButton.pressed()) {
    handleNavButton(BACK_BUTTON); //force exit active menu
    menuItems = sysMenu;
    selectedMenu = 0;
    redrawMenu(selectedMenu, CURRENT_MENU_NONE);
    currentNavButton = NO_BUTTON_PRESSED;
  }
  if (mdlButton.pressed()) {
    handleNavButton(BACK_BUTTON); //force exit active menu
    menuItems = mdlMenu;
    selectedMenu = 0;
    redrawMenu(selectedMenu, CURRENT_MENU_NONE);
    currentNavButton = NO_BUTTON_PRESSED;
  }
  if(currentNavButton){   //NO_BUTTON_PRESSED is falsy
    menuUpdateCycleCount = 0;
    handleNavButton(currentNavButton);

  } else if(currentMenu >= 0 && menuItems[currentMenu].update_period_cycles){  //if a submenu active and the submenu requests periodic updates
    menuUpdateCycleCount++;
    if (menuUpdateCycleCount >= menuItems[currentMenu].update_period_cycles){
      handleNavButton(NO_BUTTON_PRESSED);
    }
  }

  getTelemetry();
  /*if(Serial.available()){ //commands from computer

  }*/
  if(transmitActive && millis() - lastTxMillis >= msBetweenTxUpdates){
    lastTxMillis = millis();
    updateChannelValues(&streamOut);
    transmit(&streamOut, streamOutAdditionalProtocolDataLen);
  }

  SerialDebug<DEBUG_TIME>("loop time: ");
  SerialDebugln<DEBUG_TIME>(millis()-lastLoopMillis);
  lastLoopMillis = millis();
}

static int clamp(int v, int lo, int hi){
  if (v < lo) return lo;
  if (v > hi) return hi;
  return v;
}

int getOutputChannelValue(int channelIndex){
  OutputChannelDescriptor* outChannel = &outChannels[channelIndex];
  InputChannelDescriptor* inChannel = outChannel->inputChannelDescriptor;
  int value = getLatestInputData(inChannel, channelIndex);
  //scale values as needed
  return normalizeScaleRange(value, inChannel->minRange, inChannel->maxRange, outChannel->minRange, outChannel->maxRange);
}

int getFailsafeChannelValue(int channelIndex){
  InputChannelDescriptor* thisFailsafe = failsafeChannels[channelIndex];
  int value = thisFailsafe->getLatestInputData(thisFailsafe->context, thisFailsafe->id, channelIndex);
  return value;
}

void updateChannelValues(MultiProtocolStream* s){
  for(int i=0; i<MAX_CHANNELS; i++){
    int value;
    if(failsafeActive){
      value = getFailsafeChannelValue(i);
    } else {
      value = getOutputChannelValue(i);
    }
    //Serial.print("setting value:");
    //Serial.print(value);
    setChannelValue(s, i, value);
  }
}

void updateFailsafeValues(MultiProtocolStream* s){
  for(int i=0; i<MAX_CHANNELS; i++){
    int value = getFailsafeChannelValue(i);
    setChannelValue(s, i, value);
  }
  s->header.is_failsafe = 1;
  transmit(s, streamOutAdditionalProtocolDataLen);
  s->header.is_failsafe = 0;
}

void transmit(MultiProtocolStream* s, uint8_t aditional_bytes){
  uint8_t* byteArray = (uint8_t*)s;
  SerialModule.write(byteArray, (sizeof(MultiProtocolStream)-(9-aditional_bytes)));
  if(debug_level<DEBUG_TRANSMIT>()){
    printStructWithLenAsHex(&streamOut, (sizeof(streamOut)-(9-streamOutAdditionalProtocolDataLen)));
  }
}

void drawMenuItem(const char* label, int thisPageIndex, int selectedMenu, int currentMenu) {
  //starting coordinates and movement pattern for menu items
  const int xOffset[] = {0, 64};
  const int yOffsetStart = 22;
  const int ySpacing = CHAR_HEIGHT;

  u8g2.setCursor(xOffset[thisPageIndex % 2], (yOffsetStart + (thisPageIndex/2)*ySpacing));
  if (thisPageIndex == currentMenu){
    u8g2.setDrawColor(0);  //highlight currently active menu
  } else {
    u8g2.setDrawColor(1);
  }
  if (thisPageIndex == selectedMenu) {
    u8g2.print("> "); // Add a marker for the selected item
  } else {
    u8g2.print("  "); // No marker for unselected items
  }
  u8g2.print(label); // Print the label of the menu item
  u8g2.setDrawColor(1);
};

void redrawMenu(int selectedMenuItem, int activeMenuItem) {
  u8g2.setDrawColor(1);
  u8g2.drawHLine(0, 14, DISPLAY_PIXEL_WIDTH);  //line separating telemetry from menu
  u8g2.setDrawColor(0);
  u8g2.drawBox(0, 15, DISPLAY_PIXEL_WIDTH, 29); //draw blank box over menu area, region 15<y<44
  for(int menuNumber = 0; menuNumber < MENU_ITEM_COUNT; menuNumber++){
    drawMenuItem(menuItems[menuNumber].label, menuNumber, selectedMenuItem, activeMenuItem);
  }
  u8g2.setDrawColor(1);
  u8g2.drawHLine(0, 44, DISPLAY_PIXEL_WIDTH);
  u8g2.sendBuffer();
}

void drawCompactMenu(int headingMenuItem) {
  u8g2.setDrawColor(0);
  u8g2.drawBox(0, 15, DISPLAY_PIXEL_WIDTH, 30); //draw box over large menu area, region 15<y<45
  u8g2.setDrawColor(1);
  u8g2.drawHLine(0, 14, DISPLAY_PIXEL_WIDTH);  //line separating telemetry from menu
  u8g2.setCursor(0,22);
  u8g2.print(menuItems[headingMenuItem].label);
  u8g2.drawHLine(0, 25, DISPLAY_PIXEL_WIDTH);  //line separating menu heading from submenu
}

void handleNavButton(NavButton btn){
  SerialDebug<DEBUG_BUTTONS>(static_cast<uint32_t>(btn));
  if(currentMenu == -1){
    if(btn == UP_BUTTON){
      selectedMenu -= 2;
    } else if(btn == DOWN_BUTTON){
      selectedMenu += 2;
    } else if(btn == LEFT_BUTTON){
      selectedMenu -= 1;
    } else if(btn == RIGHT_BUTTON){
      selectedMenu += 1;
    } else if(btn == OK_BUTTON){
      drawCompactMenu(selectedMenu);
      currentMenu = selectedMenu;
    }
    if(selectedMenu < 0){
      selectedMenu = 0;
    }
    if(selectedMenu >= MENU_ITEM_COUNT){
      selectedMenu -= 2;
    }
  }
  //when menu is active, pass input to it;
  if (currentMenu >= 0) {
    menuItems[currentMenu].buttonHandler(currentMenu, btn);
  }
  //exit to main menu after allowing menu item function to perform cleanup as needed
  if (btn == BACK_BUTTON){
    currentMenu = -1;
  }
  if(currentMenu == -1){
    //draw full menu, and update it for current selection
    redrawMenu(selectedMenu, currentMenu);
  } else {
    //explicitly send buffer if not automatically doing so in redrawMenu()
    u8g2.sendBuffer();
  }
}


void clearMenuContents(){
    u8g2.setColorIndex(0); //erase
    u8g2.drawBox(0, 45, 128, 19);
    u8g2.setColorIndex(1); //end erase
}

void setupMenuLayout(){

  ////////model-menu items ////////
  int menuNumber = 0;
  menuItems = mdlMenu;

  strlcpy(menuItems[menuNumber].label, "Load/Save mdl", MENU_ITEM_LABEL_SIZE);
  menuItems[menuNumber].buttonHandler = modelSaveLoadMenuItemHandler;
  menuItems[menuNumber].index = menuNumber;
  menuItems[menuNumber].update_period_cycles = 0; //no updates required
  menuNumber++;

  strlcpy(menuItems[menuNumber].label, "Protocol", MENU_ITEM_LABEL_SIZE);
  menuItems[menuNumber].buttonHandler = protocolSelectMenuItemHandler;
  menuItems[menuNumber].index = menuNumber;
  menuItems[menuNumber].update_period_cycles = 50; //infrequent updates required
  menuNumber++;

  strlcpy(menuItems[menuNumber].label, "Channel Map", MENU_ITEM_LABEL_SIZE);
  menuItems[menuNumber].buttonHandler = channelMapMenuItemHandler;
  menuItems[menuNumber].index = menuNumber;
  menuItems[menuNumber].update_period_cycles = 10; //frequent updates required
  menuNumber++;

  strlcpy(menuItems[menuNumber].label, "Sub-protocol", MENU_ITEM_LABEL_SIZE);
  menuItems[menuNumber].buttonHandler = subProtocolSelectMenuItemHandler;
  menuItems[menuNumber].index = menuNumber;
  menuItems[menuNumber].update_period_cycles = 50; //infrequent updates required
  menuNumber++;

  strlcpy(menuItems[menuNumber].label, "Mixes", MENU_ITEM_LABEL_SIZE);
  menuItems[menuNumber].buttonHandler = mixerMenuItemHandler;
  menuItems[menuNumber].index = menuNumber;
  menuItems[menuNumber].update_period_cycles = 10; //frequent updates required
  menuNumber++;

  strlcpy(menuItems[menuNumber].label, "Recv select", MENU_ITEM_LABEL_SIZE);
  menuItems[menuNumber].buttonHandler = receiverSelectMenuItemHandler;
  menuItems[menuNumber].index = menuNumber;
  menuItems[menuNumber].update_period_cycles = 0; //no updates required
  menuNumber++;

  strlcpy(menuItems[menuNumber].label, "Set Failsafes", MENU_ITEM_LABEL_SIZE);
  menuItems[menuNumber].buttonHandler = failsafeSnapshotMenuItemHandler;
  menuItems[menuNumber].index = menuNumber;
  menuItems[menuNumber].update_period_cycles = 50; //infrequent updates required
  menuNumber++;


  strlcpy(menuItems[menuNumber].label, "Live Channels", MENU_ITEM_LABEL_SIZE);
  menuItems[menuNumber].buttonHandler = liveChannelViewMenuItemHandler;
  menuItems[menuNumber].index = menuNumber;
  menuItems[menuNumber].update_period_cycles = 10; //frequent updates required
  menuNumber++;
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

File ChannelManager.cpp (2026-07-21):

#include <stdint.h>
#include <cstddef>
#include <cstdio>
#include <Arduino.h>

#include "ChannelManager.h"
#include "MultiModule.h"
#include "UI.h"

extern InputChannelDescriptor* failsafeChannels[MAX_CHANNELS];

static int clamp(int v, int lo, int hi){
  if (v < lo) return lo;
  if (v > hi) return hi;
  return v;
}

//use DataProducer to get latest input data
int getLatestInputData(InputChannelDescriptor* input,int outChannelId){
  if(input == NULL){ //invalid input, null ptr
    SerialDebug<DEBUG_WARN|DEBUG_ERROR>("ERROR: tried to read input data from null pointer");
    return 0;
  }
  return input->getLatestInputData(input->context, input->id, outChannelId);
}

// Interpret context as an integer value stored via an integer-sized pointer.
// always returns the value specified by its context directly
// compatible with INPUT_FUNCTION_CONST_FIXED and INPUT_FUNCTION_CONFIG_VALUE input types
int fixedInputDataProducer(void* context, int id, int outChannelId){
  intptr_t fixedValue = (intptr_t)context;
  (void)id; // id unused in this example, supress warning with no-op
  return (int)fixedValue;
}

//a sane default input, sets the channel output to its midpoint
int defaultInputDataProducer(void* context, int id, int outChannelId){
  (void)context; // explicitly ignore incoming context
  // Provide a consistent hardcoded value for fixedInputDataProducer to return.
  // Use intptr_t cast so we can pass an integer via the void* context parameter.
  const int midpoint = NATIVE_MID_VALUE;
  return fixedInputDataProducer((void *)(intptr_t)midpoint, id, outChannelId);
}

int analogReadDataProducer(void* context, int id, int outChannelId){
  intptr_t inputPin = (intptr_t)context;
  return analogRead(inputPin);
}

int USBKeyboardNumberDataProducer(void* context, int id, int outChannelId){
  USBKeyboardContextType *usbKeyboardContext = (USBKeyboardContextType *) context;
  return usbKeyboardContext->latestValue;
}

int USBGamepadAnalogDataProducer(void* context, int id, int outChannelId){
  USBGamepadContextType *usbGamepadContext = (USBGamepadContextType *) context;
  return usbGamepadContext->parentDeviceDescriptor->latest_report[id];
}

//id is a packed value: bottom 8 bits are a bit mask, and all upper bits are byte index
int USBGamepadDigitalDataProducer(void* context, int id, int outChannelId){
  USBGamepadContextType *usbGamepadContext = (USBGamepadContextType *) context;
  if (usbGamepadContext->parentDeviceDescriptor->latest_report[id >> 8] & (id & 0xFF)){
    return 1;
  }
  return 0;
}

//overload to easily use the system's native scale 0-2047 (11 bit values)
int normalizeScaleRange(int value, int inMin, int inMax){
  return normalizeScaleRange(value, inMin, inMax, NATIVE_MIN_VALUE, NATIVE_MAX_VALUE);
}

int normalizeScaleRange(int value, int inMin, int inMax, int outMin, int outMax){
  // clamp input to its expected range
  value = clamp(value, inMin, inMax);
   if(inMin != outMin || inMax != outMax){
    // avoid division by zero if input range is empty
    int inSpan = inMax - inMin;
    if (inSpan == 0) {
      // no span: map directly to midpoint
      value = (outMin+outMax)/2;
    } else {
      // perform integer linear mapping: out = outMin + (value - inMin) * outSpan / inSpan
      int outSpan = outMax - outMin;
      value = outMin + (int)((long)(value - inMin) * outSpan / inSpan);
    }
  }
  return value;
}

int evaluateSingleChannelMixerValue(MixerChannelDescriptor* mixer, bool channel1){
  if(channel1){
    int channel1Value = getLatestInputData(mixer->inputChannel1Descriptor, -1);
    channel1Value = normalizeScaleRange(channel1Value, mixer->inputChannel1Descriptor->minRange, mixer->inputChannel1Descriptor->maxRange);
    channel1Value = channel1Value * mixer->channel1Scale/100;
    channel1Value = channel1Value + mixer->channel1Offset;
    if(mixer->channel1Invert){
      channel1Value = NATIVE_MAX_VALUE - channel1Value + NATIVE_MIN_VALUE;
    }
    return channel1Value;
  }
  //else channel 2:
  int channel2Value = getLatestInputData(mixer->inputChannel2Descriptor, -1);
  channel2Value = normalizeScaleRange(channel2Value, mixer->inputChannel2Descriptor->minRange, mixer->inputChannel2Descriptor->maxRange);
  channel2Value = channel2Value * mixer->channel2Scale/100;
  channel2Value = channel2Value + mixer->channel2Offset;
  if(mixer->channel2Invert){
    channel2Value = NATIVE_MAX_VALUE - channel2Value + NATIVE_MIN_VALUE;
  }
  return channel2Value;
}
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

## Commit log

2025-10-24 Print raw hex data from telemetry gathered
2025-10-28 integrate U8G2 display library, adjust pin assignment for glowclock board prototyping and improve portability to different hardware, and start displaying status on the display
2025-10-28 improve type safety and optimize string printing
2025-10-28 Improve printing reliability, report status when telemetry absent, start handling button inputs, and extend serial buffer to improve reliability
2025-11-07 major new feature, channel management UI and data structures, allowing configurable mapping of inputs to outputs. Currently a few default values available
2025-11-08 Add ADC input device descriptor support
2025-11-12 correct ADC range and improve fault tolerance for invalid configurations
    [ChannelManager.cpp, TelemetryLogger.ino]
2025-11-18 Implement USB keyboard number-key input channel, and framework for other USB device handling
2025-11-24 Replace hardcoded DS4 configuration to instead support arbitrary controllers with simple reconfiguration in controllerData.h. Currently implemented support for analog inputs from Sony DS4, DS5, and 8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
    [ChannelManager.cpp, ChannelManager.h, TelemetryLogger.ino]
2025-12-05 initial commit of WIP Kicad project for dedicated PCB
    [RP2350_QFN80.step, multi-module_controller_PCB.kicad_pcb, multi-module_controller_PCB.kicad_sch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]
2025-12-05 all core components placed and routed
    [multi-module_controller_PCB.kicad_pcb, multi-module_controller_PCB.kicad_sch]
2025-12-05 minor tweaks to USB port overhang positioning
    [multi-module_controller_PCB.kicad_pcb]
2025-12-18 completed layout, include production files, before adjusting component mounting
    [BOM-multi-module_controller_PCB.csv, multi-module_controller_PCB.kicad_pcb, multi-module_controller_PCB.kicad_sch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]
2025-12-19 adjust GPIO breakout, add LED, silkscreen labels, etc
    [BOM-multi-module_controller_PCB.csv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]
2025-12-19 add date to silkscreen
    [multi-module_controller_PCB-CuBottom.gbr, multi-module_controller_PCB-CuIn1.gbr, multi-module_controller_PCB-CuIn2.gbr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]
2026-02-11 add hardware tests for new board
    [multi-module_controller_PCB.kicad_sch]
2026-02-11 Implement pin-remapping and adjustments for new PCB, add support for both USB A and C ports (configured at compile-time by active_usb_port for now). Buttons, i2c display, USB A, USB C, all functional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
    [multi-module_controller_PCB.kicad_pcb, multi-module_controller_PCB.kicad_sch]
2026-02-12 start on revisions for REV2 board design
    [BOM-multi-module_controller_PCB.csv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]
2026-02-12 Split main menu into sys and model menus, implement USB port switching menu and functionality, log detailed device descriptor information
2026-03-25 Improve cleanup of disconnected USB devices, including assigned output channels.
2026-05-07 update software to use SPI LCD at up to 8MHz
2026-05-07 Update PCB with improved bulk capacitors for VBus, increased mounting hole diameter for display, and offset multi-module connector further away from USB A port
    [multi-module_controller_PCB.kicad_pcb, multi-module_controller_PCB.kicad_sch]
2026-05-08 update PCB to drive OLED from 3v3 rail
    [multi-module_controller_PCB.kicad_pcb, multi-module_controller_PCB.kicad_sch]
2026-05-08 Add alternative SPI pinout configurations, rearrange menu, implement sample layout for mixes menu
2026-05-08 Update PCB files for v1.1
    [BOM-multi-module_controller_PCB.csv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]
2026-05-13 add u8g2PrintPadding function to print a 1 pixel padding before/after text to improve readability with highlighted text
2026-05-16 Fix model button menu bug and rearrange mixer menu layout prototype
    [TelemetryLogger.ino]
2026-05-17 extensive reworking and start on implementation of mixer interface, currently allows selecting mix number, operation, and both input sources
    [ChannelManager.cpp, ChannelManager.h, TelemetryLogger.ino]
2026-05-29 Replace Serial.print() with new SerialDebug<LOG_LEVEL_FLAG> syntax, allowing easy removal of unneded/excessively verbose serial logging by category.
    [TelemetryLogger.ino, UI.h, usbh_helper.h]
2026-05-31 add scripts directory and use arduino-cli to compile boards for ease of automation and debugging
    [rp2350-debugprobe.cfg]
2026-05-31 Fix double-free bug when deconstructing USB device, add details to readme with debugging steps
    [ChannelManager.cpp, ChannelManager.h]
2026-05-31 start preparing PCB schematic for SD card in version 1.1
    [multi-module_controller_PCB.kicad_pcb, multi-module_controller_PCB.kicad_sch]
2026-06-01 Add SD Card slot to underside of board, wired for use with SPI1. Reconfigure button pinout and use J10 pins for this purpose
    [multi-module_controller_PCB.kicad_pcb, multi-module_controller_PCB.kicad_sch]
2026-06-04 fully implement failsafe handling, save failsafe values to profiles, send failsafe value to multi-module, and automatically restore failsafe value when USB input lost
    [ChannelManager.cpp, ChannelManager.h, GamesteerRC.ino]
2026-06-04 implement failsafe values for mixer when input sources not present
    [ChannelManager.cpp, ChannelManager.h, GamesteerRC.ino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]
2026-06-12 Update todo and done details on schematic, start on 3D model for case
    [Case.FCStd, PCBv1-1.step, multi-module_controller_PCB.kicad_pcb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]
2026-07-08 Start on logic for handling defaults menu, track currently active model index
2026-07-08 Load/save defaults now functional, and defaults are loaded at boot. Also update to latest iteration of 3D model
    [Case.FCStd]
2026-07-08 Fix USB handling when loading defaults to allow USB device to initialize properly, and add progress prints during startup
    [GamesteerRC.ino]
2026-07-18 fix USB failsafe for channels beyond channel 0
    [ChannelManager.cpp]
2026-07-21 Fix incorrect offset when invert enabled on inputs that have a non-11 bit range
    [ChannelManager.cpp]
2026-07-21 add documentation of reverse-engineered HID input layout for PS4 controller
    [PS4 HID report layout.xlsx]
2026-07-21 Add support for digital button inputs from game controllers, fully implemented for PS4 controller
2026-07-23 Finalized V2 schematic and PCB
    [multi-module_controller_PCB.kicad_pcb, multi-module_controller_PCB.kicad_sch]
